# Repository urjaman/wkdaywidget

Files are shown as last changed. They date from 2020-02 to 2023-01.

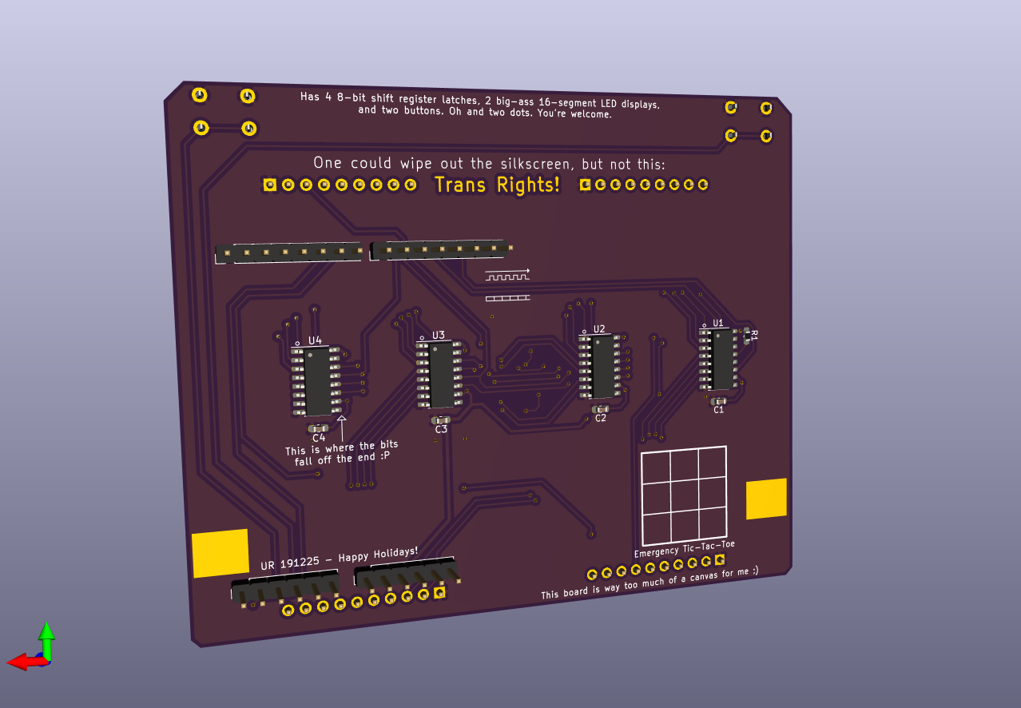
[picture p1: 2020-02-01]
kicad-hw/pcb-rear-3drender.png

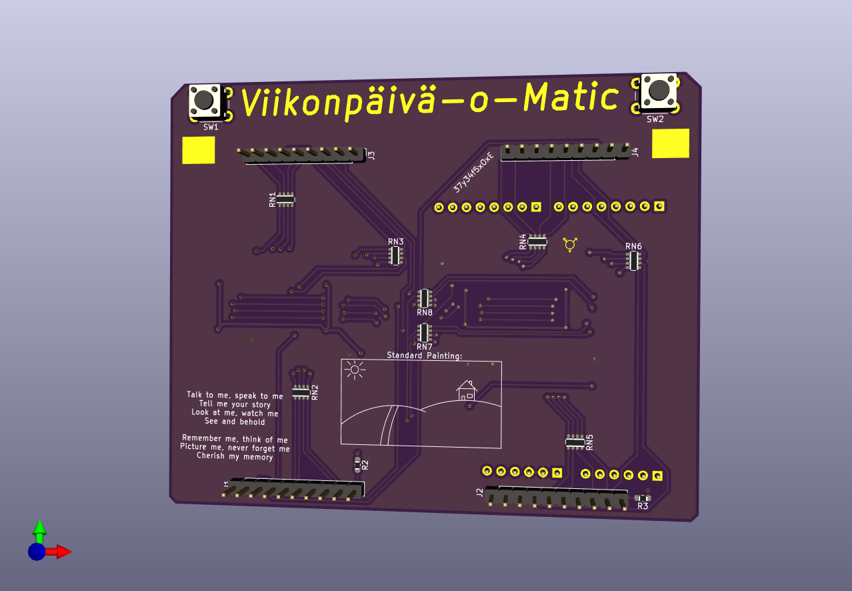
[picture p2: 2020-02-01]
kicad-hw/pcb-front-3drender.png

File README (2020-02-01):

The Weekday-o-matic aka wkdaywidget
-----------------------------------

This is a rather gigantic "Arduino" shield,
to make a rather big display showing the
current day of week. Or well atleast the
firmware for running it and a design
for the PCB on it.

BOM for the whole thing:
- An ATmega328-based arduino (Uno R3 clone)
- A DS1307 RTC module (with backup battery) soldered into the arduino I2C pins
	(or a datalogger shield, do not insert an SD card to that tho)
- the PCB (in hw-kicad/)
- some 0.1" headers
- 2 big common cathode 16-segment displays:
https://www.ebay.com/itm/2-3-16Segment-1-Digit-Bit-RED-LED-Display-Red-Signs-2-3inch-16-segment-CC-CA/254326426921

- 4 SO-16 74HC595D shift register & latches
- 5 4x0603 100ohm resistor arrays (RN1, RN2, RN4, RN5, RN7)
- 3 4x0603 220ohm resistor arrays (RN3, RN6, RN8)
- 2 560ohm 0603 resistors
- 1 100kohm 0603 resistor
- 4 0.1uF 0603 capacitors
- 2 "6mm" "standard" PCB push buttons

NOTE/WARNING: in the current PCB the spacing between the rows on the big displays is too big (tall, whatever),
though it was possible to bend the pins on the display enough to push them in.

If you intend to build this, i recommend you first get the displays and measure 
the actual row spacing (because i did it to the spec on ebay, 62mm, but no dice)
and adjust the PCB design appropriately (or email me for me to do that).
I'd do it but I already soldered my displays down (so hard to measure) + am lazy.
(This is mostly a note to self in case i ever get more PCBs :P)

The firmware defaults to finnish, but just adjust the includes 
in the beginning of ui.c to get english.

PRs accepted if you want to add a header for your own language :)

To clone this repo, remember to use --recursive since it contains a submodule.
You will need an AVR toolchain (avr-gcc, avr-libc etc) to build the firmware,
and avrdude to program it.

The targets are just "make" to build the firmware and "make program" for the
programming. Check the Makefile that you have the correct serial device
etc first.

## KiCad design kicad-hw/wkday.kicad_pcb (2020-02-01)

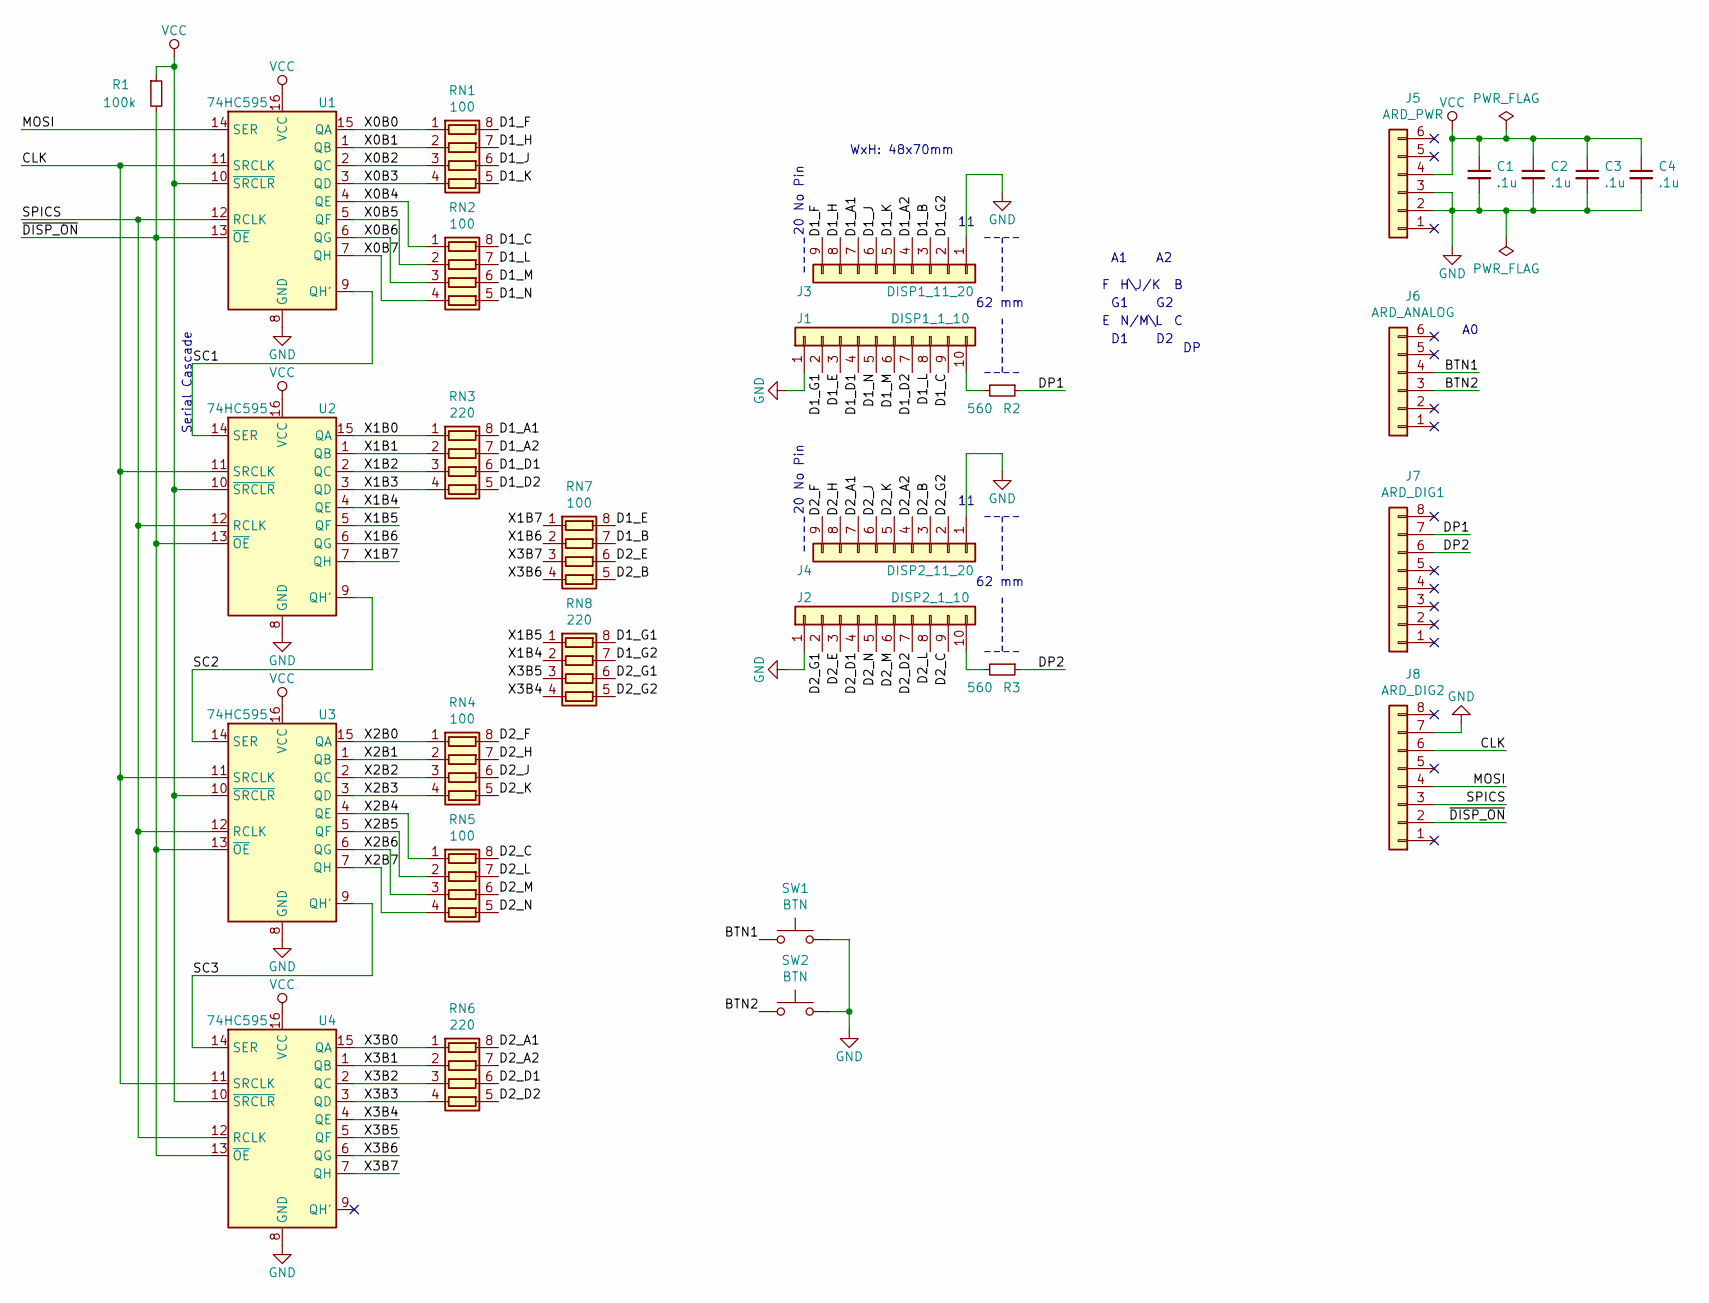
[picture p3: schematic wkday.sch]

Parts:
C1, C2, C3, C4: .1u; C_0603_1608Metric_Pad1.05x0.95mm_HandSolder
J1: DISP1_1_10; PinHeader_1x10_P2.54mm_Vertical
J2: DISP2_1_10; PinHeader_1x10_P2.54mm_Vertical
J3: DISP1_11_20; PinHeader_1x09_P2.54mm_Vertical
J4: DISP2_11_20; PinHeader_1x09_P2.54mm_Vertical
J5: ARD_PWR; PinHeader_1x06_P2.54mm_Vertical
J6: ARD_ANALOG; PinHeader_1x06_P2.54mm_Vertical
J7: ARD_DIG1; PinHeader_1x08_P2.54mm_Vertical
J8: ARD_DIG2; PinHeader_1x08_P2.54mm_Vertical
R1: 100k; R_0603_1608Metric_Pad1.05x0.95mm_HandSolder
R2, R3: 560; R_0603_1608Metric_Pad1.05x0.95mm_HandSolder
RN1, RN2, RN4, RN5, RN7: 100; R_Array_Concave_4x0603
RN3, RN6, RN8: 220; R_Array_Concave_4x0603
SW1, SW2: BTN; SW_PUSH_6mm
U1, U2, U3, U4: 74HC595; SOIC-16_3.9x9.9mm_P1.27mm

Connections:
/BTN1: J6.4, SW1.1
/BTN2: J6.3, SW2.1
/CLK: J8.6, U1.11 (SRCLK), U2.11 (SRCLK), U3.11 (SRCLK), U4.11 (SRCLK)
/D1_A1: J3.7, RN3.8 (R1.2)
/D1_A2: J3.4, RN3.7 (R2.2)
/D1_B: J3.3, RN7.7 (R2.2)
/D1_C: J1.9, RN2.8 (R1.2)
/D1_D1: J1.4, RN3.6 (R3.2)
/D1_D2: J1.7, RN3.5 (R4.2)
/D1_E: J1.3, RN7.8 (R1.2)
/D1_F: J3.9, RN1.8 (R1.2)
/D1_G1: J1.2, RN8.8 (R1.2)
/D1_G2: J3.2, RN8.7 (R2.2)
/D1_H: J3.8, RN1.7 (R2.2)
/D1_J: J3.6, RN1.6 (R3.2)
/D1_K: J3.5, RN1.5 (R4.2)
/D1_L: J1.8, RN2.7 (R2.2)
/D1_M: J1.6, RN2.6 (R3.2)
/D1_N: J1.5, RN2.5 (R4.2)
/D2_A1: J4.7, RN6.8 (R1.2)
/D2_A2: J4.4, RN6.7 (R2.2)
/D2_B: J4.3, RN7.5 (R4.2)
/D2_C: J2.9, RN5.8 (R1.2)
/D2_D1: J2.4, RN6.6 (R3.2)
/D2_D2: J2.7, RN6.5 (R4.2)
/D2_E: J2.3, RN7.6 (R3.2)
/D2_F: J4.9, RN4.8 (R1.2)
/D2_G1: J2.2, RN8.6 (R3.2)
/D2_G2: J4.2, RN8.5 (R4.2)
/D2_H: J4.8, RN4.7 (R2.2)
/D2_J: J4.6, RN4.6 (R3.2)
/D2_K: J4.5, RN4.5 (R4.2)
/D2_L: J2.8, RN5.7 (R2.2)
/D2_M: J2.6, RN5.6 (R3.2)
/D2_N: J2.5, RN5.5 (R4.2)
/DP1: J7.7, R2.1
/DP2: J7.6, R3.1
/MOSI: J8.4, U1.14 (SER)
/SC1: U1.9 (QH'), U2.14 (SER)
/SC2: U2.9 (QH'), U3.14 (SER)
/SC3: U3.9 (QH'), U4.14 (SER)
/SPICS: J8.3, U1.12 (RCLK), U2.12 (RCLK), U3.12 (RCLK), U4.12 (RCLK)
/X0B0: RN1.1 (R1.1), U1.15 (QA)
/X0B1: RN1.2 (R2.1), U1.1 (QB)
/X0B2: RN1.3 (R3.1), U1.2 (QC)
/X0B3: RN1.4 (R4.1), U1.3 (QD)
/X0B4: RN2.1 (R1.1), U1.4 (QE)
/X0B5: RN2.2 (R2.1), U1.5 (QF)
/X0B6: RN2.3 (R3.1), U1.6 (QG)
/X0B7: RN2.4 (R4.1), U1.7 (QH)
/X1B0: RN3.1 (R1.1), U2.15 (QA)
/X1B1: RN3.2 (R2.1), U2.1 (QB)
/X1B2: RN3.3 (R3.1), U2.2 (QC)
/X1B3: RN3.4 (R4.1), U2.3 (QD)
/X1B4: RN8.2 (R2.1), U2.4 (QE)
/X1B5: RN8.1 (R1.1), U2.5 (QF)
/X1B6: RN7.2 (R2.1), U2.6 (QG)
/X1B7: RN7.1 (R1.1), U2.7 (QH)
/X2B0: RN4.1 (R1.1), U3.15 (QA)
/X2B1: RN4.2 (R2.1), U3.1 (QB)
/X2B2: RN4.3 (R3.1), U3.2 (QC)
/X2B3: RN4.4 (R4.1), U3.3 (QD)
/X2B4: RN5.1 (R1.1), U3.4 (QE)
/X2B5: RN5.2 (R2.1), U3.5 (QF)
/X2B6: RN5.3 (R3.1), U3.6 (QG)
/X2B7: RN5.4 (R4.1), U3.7 (QH)
/X3B0: RN6.1 (R1.1), U4.15 (QA)
/X3B1: RN6.2 (R2.1), U4.1 (QB)
/X3B2: RN6.3 (R3.1), U4.2 (QC)
/X3B3: RN6.4 (R4.1), U4.3 (QD)
/X3B4: RN8.4 (R4.1), U4.4 (QE)
/X3B5: RN8.3 (R3.1), U4.5 (QF)
/X3B6: RN7.4 (R4.1), U4.6 (QG)
/X3B7: RN7.3 (R3.1), U4.7 (QH)
/~DISP_ON: J8.2, R1.2, U1.13 (~OE), U2.13 (~OE), U3.13 (~OE), U4.13 (~OE)
GND: C1.2, C2.2, C3.2, C4.2, J1.1, J2.1, J3.1, J4.1, J5.2, J5.3, J8.7, SW1.2, SW2.2, U1.8 (GND), U2.8 (GND), U3.8 (GND), U4.8 (GND)
unnamed: J1.10, R2.2
unnamed: J2.10, R3.2
VCC: C1.1, C2.1, C3.1, C4.1, J5.4, R1.1, U1.10 (~SRCLR), U1.16 (VCC), U2.10 (~SRCLR), U2.16 (VCC), U3.10 (~SRCLR), U3.16 (VCC), U4.10 (~SRCLR), U4.16 (VCC)

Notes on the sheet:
62 mm
20 No Pin
H\J/K
N/M\L
Serial Cascade
WxH: 48x70mm

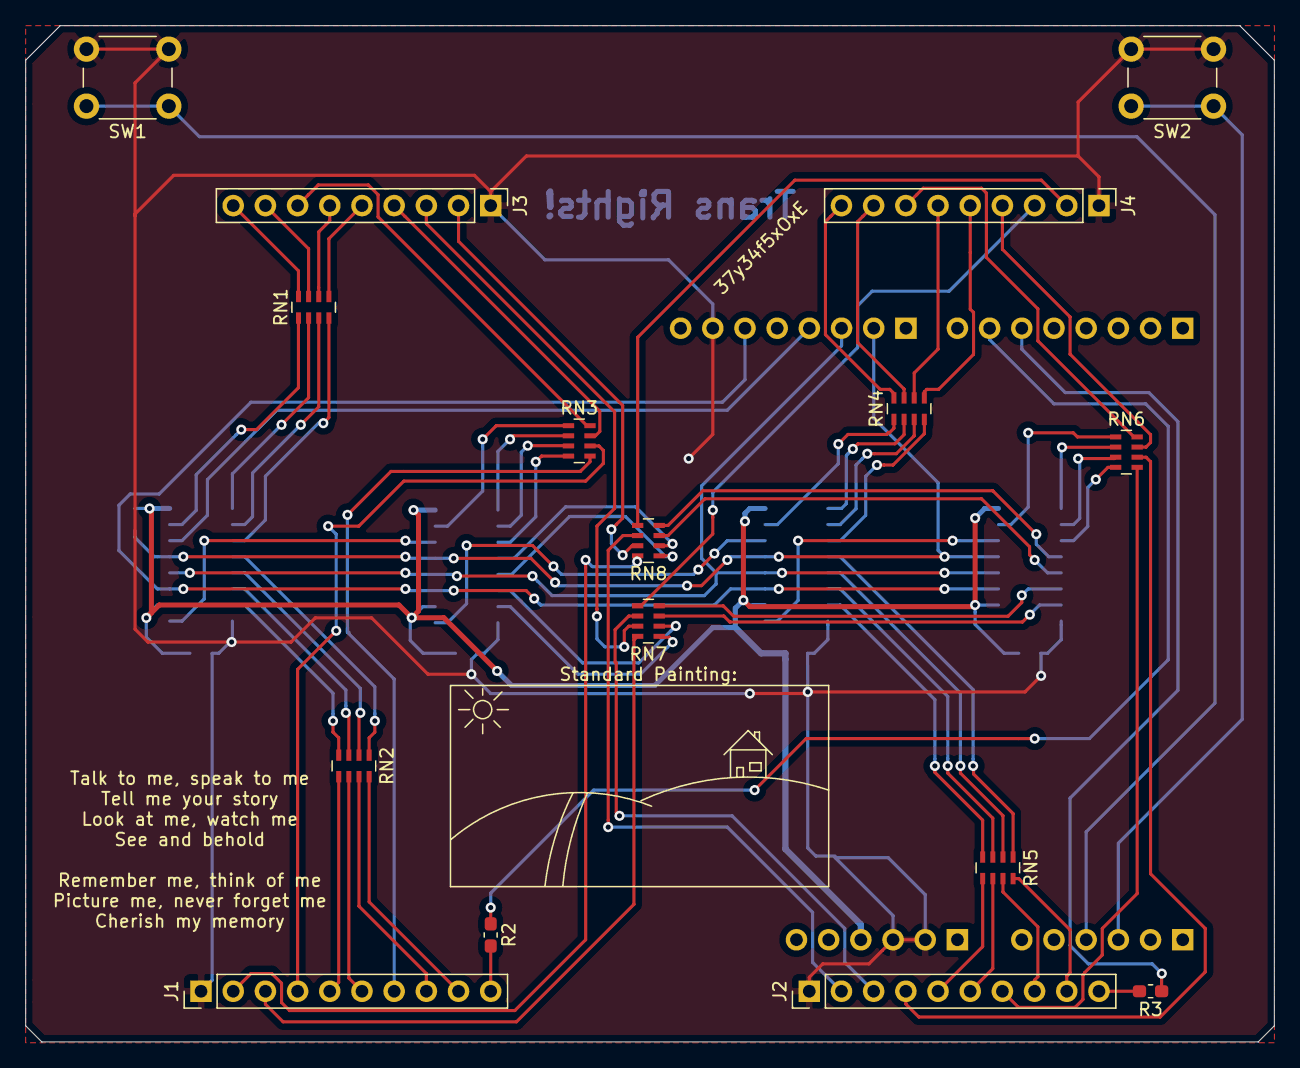
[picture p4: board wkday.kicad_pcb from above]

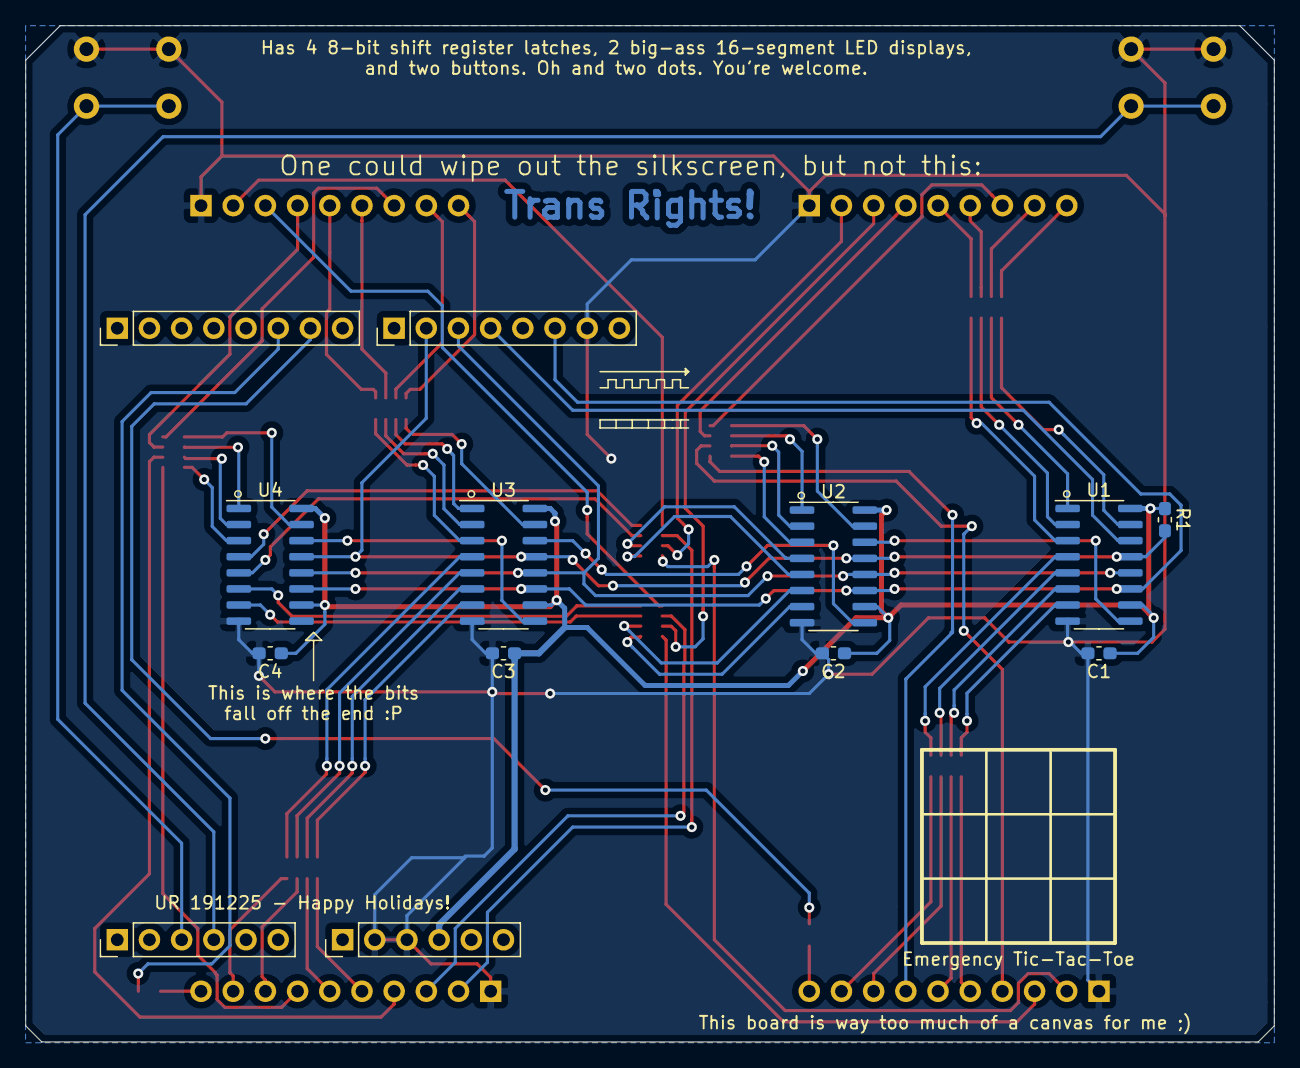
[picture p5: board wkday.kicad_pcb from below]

Board: 2 copper layers, 98.5 x 80.2 mm, 29 parts (13 on the bottom side), 79 nets.

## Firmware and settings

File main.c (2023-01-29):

/*
 * Copyright (C) 2009,2020 Urja Rannikko <urjaman@gmail.com>
 *
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
 */

#include "main.h"
#include "i2c.h"
#include "uart.h"
#include "ciface.h"
#include "buttons.h"
#include "timer.h"
#include "console.h"
#include "dsp16seg.h"
#include "ui.h"
#include "rtc.h"


void cli_bgloop(void) {
	timer_run();
}

/* Avoid accidental reentry into ciface while calling UI functions from ciface */
/* No multithreading going on here so a simple variable will do. */
static uint8_t ciface_lock = 0;
void mini_mainloop(void) {
	cli_bgloop();
	if (!ciface_lock) {
		ciface_lock = 1;
		ciface_run();
		ciface_lock = 0;
	}
}

void main (void) __attribute__ ((noreturn));


void main(void) {
	uart_init();
	ciface_init();
	timer_init();
	buttons_init();
	dsp16seg_init();
	i2c_init();
	rtc_init();
	ui_init();
	for(;;) {
		mini_mainloop();
		ui_run();
	}
}

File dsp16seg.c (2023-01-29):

/*
 * Copyright (C) 2020 Urja Rannikko <urjaman@gmail.com>
 *
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
 */

#include "main.h"
#include "dsp16seg.h"

#define DISP_CHRS DSP16SEG_DISP_CHARS

#define S_F  0x0001
#define S_H  0x0002
#define S_J  0x0004
#define S_K  0x0008
#define S_C  0x0010
#define S_L  0x0020
#define S_M  0x0040
#define S_N  0x0080

#define S_A1 0x0100
#define S_A2 0x0200
#define S_D1 0x0400
#define S_D2 0x0800
#define S_G2 0x1000
#define S_G1 0x2000
#define S_B  0x4000
#define S_E  0x8000

#define S_DP1 _BV(COM0A1)
#define S_DP2 _BV(COM0B1)

/* Only the range from 0x20 to 0x5F, that is
 * some symbols, numbers, and big letters */
static const uint16_t asc2segtab[64] PROGMEM = {
	// Some of the symbol space...
	0,		// 0x20 ' '
	S_J | S_D1,	// !
	S_F | S_B,	// "
	0,		// #

	S_J | S_M | S_A1 | S_A2 | S_F | S_G1 | S_G2 | S_C | S_D2 | S_D1, // $
	S_N | S_K | S_A1 | S_D2, // %
	S_L | S_H | S_A1 | S_J | S_N | S_D1 | S_D2 | S_C, // &
	S_B,		// '

	S_K | S_L, // (
	S_H | S_N, // )
	S_H | S_J | S_K | S_G1 | S_G2 | S_N | S_M | S_L, // *
	S_J | S_M | S_G1 | S_G2, // +

	S_N,			// ','
	S_G1 | S_G2,	// '-'
	0,			// '.' (implemented using the DP leds seperately)
	S_N | S_K,		// '/'

	// Numbers
	S_A1 | S_A2 | S_B | S_C | S_D2 | S_D1 | S_E | S_F, // 0
	S_B | S_C, // 1 (in 7-seg style)
	S_A1 | S_A2 | S_B | S_G2 | S_G1 | S_E | S_D1 | S_D2, // 2
	S_A1 | S_A2 | S_B | S_G2 | S_G1 | S_C | S_D1 | S_D2, // 3
	S_F | S_G1 | S_G2 | S_B | S_C, // 4
	S_A1 | S_A2 | S_F | S_G1 | S_G2 | S_C | S_D2 | S_D1, // 5
	S_A1 | S_A2 | S_F | S_E | S_D1 | S_D2 | S_C | S_G1 | S_G2, // 6
	S_A1 | S_A2 | S_B | S_C, // 7
	S_F | S_B | S_E | S_C | S_A1 | S_A2 | S_G1 | S_G2 | S_D1 | S_D2, // 8
	S_A1 | S_A2 | S_F | S_B | S_G1 | S_G2 | S_C | S_D1 | S_D2, // 9

	// Uhh...

	S_G1 | S_D1, // :
	S_A1 | S_N, // ;
	S_K | S_G2 | S_L, // <
	S_G1 | S_G2 | S_D1 | S_D2, // =
	S_H | S_G1 | S_N, // >
	S_A1 | S_A2 | S_B | S_G2 | S_M, // ?

	S_G2 | S_B | S_A2 | S_A1 | S_F | S_E | S_D1 | S_D2, // @

	// Letters
	S_F | S_A1 | S_A2 | S_B | S_G1 | S_G2 | S_E | S_C, // A
	S_A1 | S_A2 | S_B | S_C | S_D2 | S_D1 | S_J | S_M | S_G1 | S_G2, // B
	S_A1 | S_A2 | S_F | S_E | S_D1 | S_D2,		   // C
	S_A1 | S_A2 | S_B | S_C | S_D2 | S_D1 | S_J | S_M, // D
	S_A1 | S_A2 | S_F | S_G1 | S_G2 | S_E | S_D1 | S_D2, // E
	S_A1 | S_A2 | S_F | S_G1 | S_G2 | S_E, // F
	S_G2 | S_C | S_D2 | S_D1 | S_E | S_F | S_A1 | S_A2, // G
	S_F | S_B | S_G1 | S_G2 | S_E | S_C, // H
	S_J | S_M, // I
	S_J | S_M | S_D1, // J
	S_F | S_E | S_G1 | S_K | S_L, // K
	S_F | S_E | S_D1 | S_D2, // L
	S_E | S_F | S_H | S_K | S_B | S_C, // M
	S_E | S_F | S_H | S_L | S_C | S_B, // N
	S_A1 | S_A2 | S_B | S_C | S_D2 | S_D1 | S_E | S_F, // O
	S_A1 | S_A2 | S_F | S_B | S_G1 | S_G2 | S_E, // P
	S_A1 | S_A2 | S_B | S_C | S_D2 | S_D1 | S_E | S_F | S_L, // Q
	S_A1 | S_A2 | S_F | S_B | S_G1 | S_G2 | S_E | S_L, // R
	S_A1 | S_A2 | S_F | S_G1 | S_G2 | S_C | S_D2 | S_D1, // S
	S_A1 | S_A2 | S_J | S_M, // T
	S_F | S_B | S_E | S_C | S_D1 | S_D2, // U
	S_F | S_E | S_N | S_K, // V
	S_F | S_B | S_E | S_C | S_N | S_L, // W
	S_H | S_K | S_N | S_L,
	S_H | S_K | S_M, // Y
	S_A1 | S_A2 | S_K | S_N | S_D1 | S_D2, // Z

	// A few extra symbols
	S_A2 | S_J | S_M | S_D2, // [
	S_H | S_L, // '\'
	S_A1 | S_J | S_M | S_D1, // ]
	S_N | S_L, // ^
	S_D1 | S_D2 // _
};


/* Legend for help with the segments:
  x-A1-x-A2-x
  |\   |   /|
  F H  J  K B
  |  \ | /  |
  x-G1-x-G2-x
  |  / | \  |
  E N  M  L C
  |/   |   \|
  x-D1-x-D2-x
*/


static void spi_shove(uint8_t data) {
	uint8_t st;
	do {
		SPDR = data;
		st = SPSR;
	} while(st & _BV(WCOL));
}

static void spi_done(void) {
	uint8_t st;
	volatile uint8_t dummy;
	do {
		st = SPSR;
		dummy = SPDR;
	} while (!(st & _BV(SPIF)));
	_delay_us(2);
	(void)dummy;
}

static void dsp16seg_update(uint16_t *segdat, uint8_t dp) {
	do {
		uint8_t r = TCCR0A & ~(S_DP1 | S_DP2);
		r |= dp;
		TCCR0A = r;
		if (!(dp & S_DP1)) {
			PORTD &= ~_BV(6);
		}
		if (!(dp & S_DP2)) {
			PORTD &= ~_BV(5);
		}
	} while(0);
	PORTB &= ~_BV(2);
	for (int8_t n=DISP_CHRS-1;n>=0;n--) {
		spi_shove(segdat[n] >> 8);
		spi_shove(segdat[n] & 0xFF);
	}
	spi_done();
	PORTB |= _BV(2);
}

void dsp16seg_set_brightness(uint8_t br) {
	/* Main display brightness is PB1/OC1A and inverted */
	/* Decimal points are DP1 = OCOA/PD6 and DP2 = OCOB/PD5 */
	OCR0A = br;
	OCR0B = br;
	OCR1A = br;
}


void dsp16seg_init(void) {
	uint16_t clr[DISP_CHRS] = { 0 };

	/* Set correct default states on the SPI/PORTB */
	PORTB = _BV(2) | _BV(1);
	/* CLK, MOSI, CS (latch clock), ~DISP_ON */
	DDRB = _BV(5) | _BV(3) | _BV(2) | _BV(1);

	/* Enable drive on the decimal point lines */
	DDRD |= _BV(5);
	DDRD |= _BV(6);

	/* Enable the SPI peripheral */
	SPCR = _BV(SPE) | _BV(MSTR);
	SPSR = _BV(SPI2X);

	/* DP PWM to Fast PWM mode */
	TCCR0A |= _BV(WGM01) | _BV(WGM00);

	/* SPI and DP PWM is ready, clear the display to avoid glitches */
	dsp16seg_update(clr, 0);

	/* Timer 1 into similar 8-bit PWM mode as Timer 0 (except a bit slower because geeze) */
	TCCR1A = _BV(COM1A1) | _BV(COM1A0) | _BV(WGM10);
	TCCR1B = _BV(WGM12) | _BV(CS11);

	/* Set a sensible brightness */
	dsp16seg_set_brightness(8);
}


uint8_t dsp16seg_settext(const char *txt) {
	uint16_t segdat[DISP_CHRS] = { 0 };
	uint8_t dp = 0;
	uint8_t sn = 0;
	uint8_t tn = 0;
	for (;txt[tn];tn++) {
		uint8_t c = toupper(txt[tn]);
		if ((c < 0x20) || (c >= 0x60)) c = ' ';
		if (c == '.') {
			if (!sn) sn++;
			if ((sn == 1)&&(dp & S_DP1)) sn++;
			if ((sn == 2)&&(dp & S_DP2)) break;
			if (sn == 1) dp |= S_DP1;
			else dp |= S_DP2;
			continue;
		}
		if (sn == 2) break;
		segdat[sn++] = pgm_read_word(&(asc2segtab[c - 0x20]));
	}
	dsp16seg_update(segdat, dp);
	return tn;
}

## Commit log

2020-02-01 Do as much power mgmt as we need on this thing
    Just idle the AVR, and remove the "system idle" management of the datalogger
    ("system idle" was for deep sleeping)
2020-02-01 Add the kicad PCB design that goes with this (also gitignore)
    [wkday-B_Cu.gbr, wkday-B_Mask.gbr, wkday-B_SilkS.gbr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]

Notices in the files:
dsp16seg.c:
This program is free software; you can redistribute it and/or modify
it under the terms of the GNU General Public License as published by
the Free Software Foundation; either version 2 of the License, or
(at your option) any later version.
